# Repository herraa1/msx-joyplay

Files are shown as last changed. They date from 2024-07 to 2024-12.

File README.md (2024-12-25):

# Sony Playstation controller adapter for MSX (msx-joyplay) v2

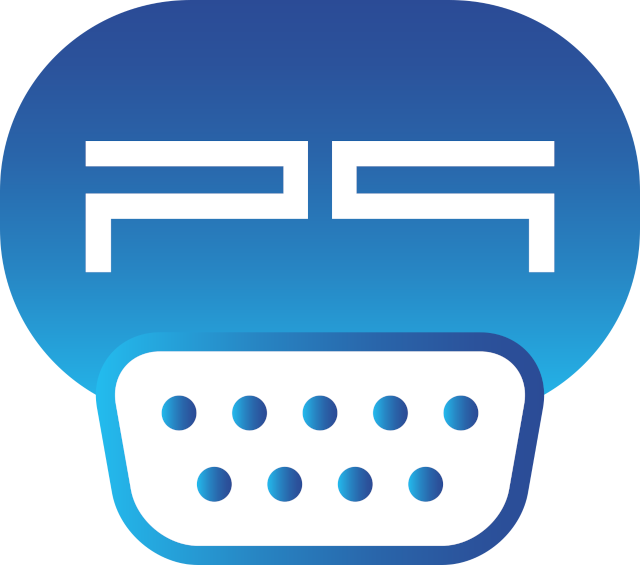
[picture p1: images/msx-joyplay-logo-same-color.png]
[](images/msx-joyplay-logo-same-color.png)

Connect [Sony PlayStation controllers](https://en.wikipedia.org/wiki/PlayStation_(console)#Controllers) to [MSX computers](https://www.msx.org/wiki/).

> [!NOTE]
>
> No build instructions are yet provided, but if you are brave enough go for the [recommended build](#recommended-build).
>

## Introduction

The msx-joyplay v2 is an adapter that allows connecting Sony PlayStation controllers to [MSX general purpose I/O ports](https://www.msx.org/wiki/General_Purpose_port).

The main features of the msx-joyplay v2 adapter are:
* small footprint
* made of widely available electronic components
* behaves as a cord extension between the MSX computer and the Sony PlayStation controller
* uses a female standard DE9 connector on the adapter's MSX joystick side
* uses a PlayStation Controller socket on the adapter's Sony PlayStation controller side
* no need for external power supply, the adapter draws current from the MSX port
* low power consumption (<20mA)
* serial debug provides information about the operation of the adapter

## [Hardware](hardware/kicad/)

The msx-joyplay v2 adapter uses an [Atmega328p](https://en.wikipedia.org/wiki/ATmega328) to convert the [Sony PlayStation SPI-like controller signalling](https://store.curiousinventor.com/guides/PS2) to the [MSX joystick standard signalling](https://www.msx.org/wiki/Joystick_control).

A two-sided printed circuit board (PCB) is used to put together all components:
* An Atmega328p as the main MCU working at +3.3V and clocked at 8MHz
* An AMS1117-3.3 regulator to convert the 5V from the joystick port to the 3.3V used for the Atmega328p chip and the PlayStation controller
* Two 74LS03 quad 2-input NAND gates with open collectors to completely mimic the standard MSX joystick behavior
* A PTC fuse to minimize damage to the MSX computer in case something goes wrong with the board
* Several additional required components (crystal, diode, leds, resistors, ceramic capacitors and a tantalum capacitor)
* An angled PSX socket is used to directly connect the Sony PlayStation controller
* A PH2.0 connector is used to connect the MSX cable extension
* A 2.54 pitch debug header is added for serial debug and programming
* An ICSP header is provided for burning a bootloader or to flash the chip using a hardware programmer

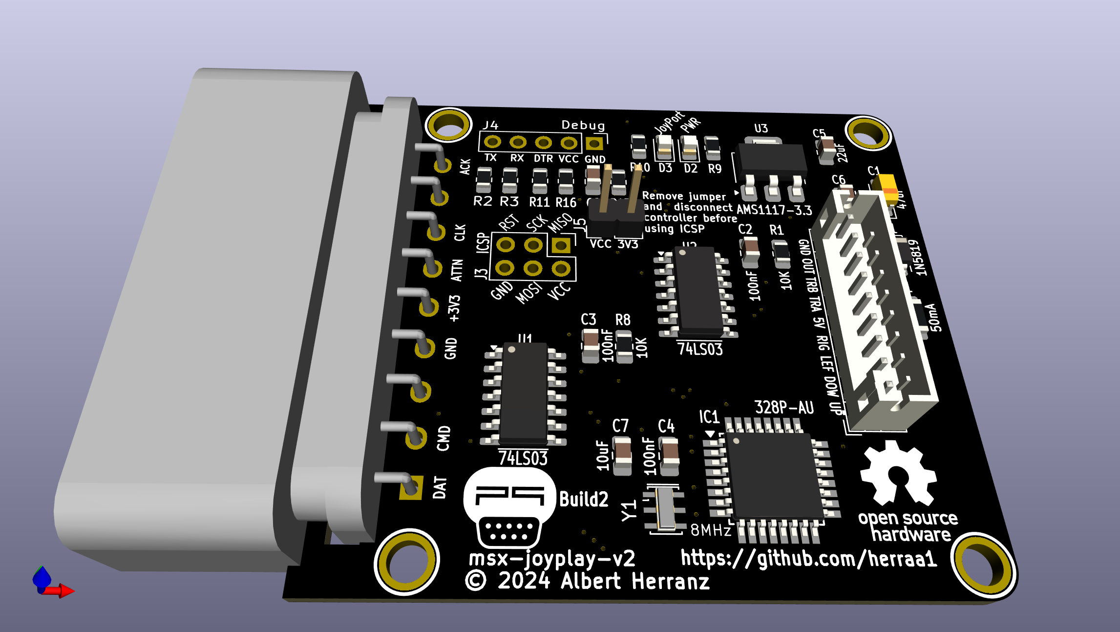
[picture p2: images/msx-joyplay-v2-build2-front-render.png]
[](images/msx-joyplay-v2-build2-front-render.png)
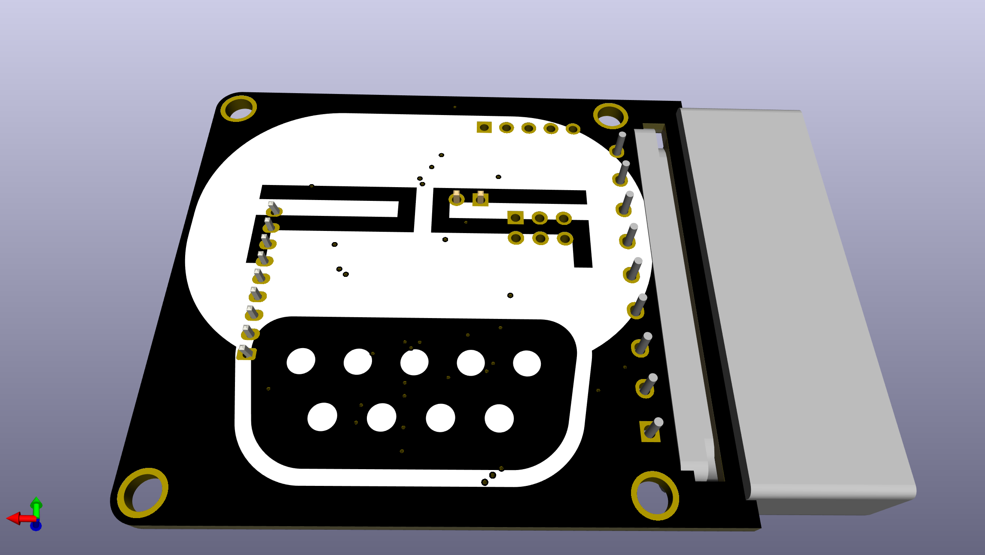
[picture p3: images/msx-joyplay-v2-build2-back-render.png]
[](images/msx-joyplay-v2-build2-back-render.png)

Connection to the MSX general purpose I/O port is implemented using a DE9 joystick extension cable with a female DE9 connector on one side and a loose end on the other side.
The MSX joystick extension cable loose end is wired according to the following pinout mapping.

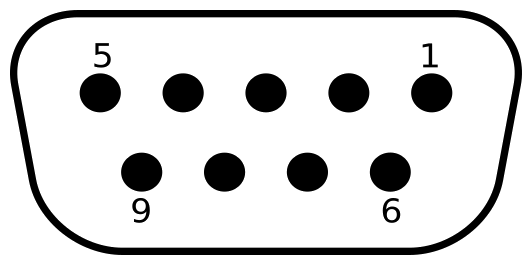
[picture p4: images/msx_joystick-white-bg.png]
| [](images/msx_joystick-white-bg.png) |
|:--|
| MSX joystick connector pinout, from controller plug side |

| MSX side pin | Cable color (may vary) | Signal |
| --- | --- | --- |
| 5 | Brown | +5v |
| 4 | Orange | RIGHT  |
| 3 | Grey | LEFT |
| 2 | Black | DOWN |
| 1 | Red | UP |
| 6 | Green | TRIGA  |
| 7 | White | TRIGB  |
| 8 | Blue | OUT |
| 9 | Yellow | GND |

The msx-joyplay-v2 is fully compatible with MSX joysticks and honors the pin8 (OUT) signal.

The adapter uses open collector outputs (using 74LS03 Quad 2-Input NAND gates with open collector outputs) which makes the adapter safer [^2] than the
standard MSX joystick schematic depicted in the MSX Technical Data Book, as it avoids a series of undesired conditions that can lead to bus contention/short circuits.

Power is drawn from the +5V signal of the MSX general purpose I/O port, which is capable of delivering up to 50mA [^1].
The msx-joyplay v2 draws below 20mA from the port when a controller is connected, so it is on the safe side. Anyway, the msx-joyplay adapter uses a Positive Temperature Coeficient (PTC) resettable fuse of 50mA (F1) to limit current in case something goes wrong.

Also on the power side, a [1N5819 Schottky diode](https://www.diodes.com/assets/Datasheets/1N5819HW.pdf) (D1) is used to avoid leaking current from the msx-joyplay adapter to the MSX in case power is applied to one of the VCC pins available on the ICSP or Debug headers while the adapter is plugged into an MSX.

Connection to the Sony PlayStation controller is done via a Sony PlayStation controller socket.

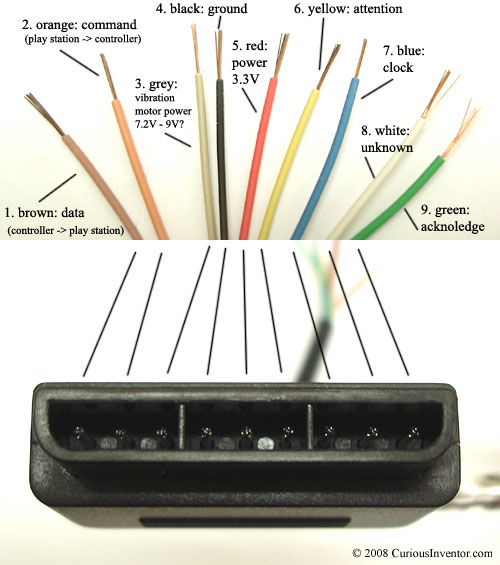
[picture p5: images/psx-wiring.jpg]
| [](images/psx-wiring.jpg) |
|:--|
| Sony PlayStation connector pinout, from Sony PlayStation controller side |

| PSX socket pin | Cable color official | Signal | Comment |
| --- | ---| --- | --- |
| 1 | Brown | DAT  / MISO  | data line, controller -> msx, open-collector signal |
| 2 | Orange | CMD  / MOSI  | cmd line, msx -> controller, uses 3v3 logic |
| 3 | Grey | RUMBLE POWER | 7.6V power, not used (rumble not supported) |
| 4 | Black | GND | ground |
| 5 | Red | +3V3 | +3V3 power |
| 6 | Yellow | ATTN / SS | select line, msx -> controller, uses 3v3 logic |
| 7 | Blue | CLK  / SCK | clock line, msx -> controller, uses 3v3 logic |
| 8 | n/c | | |
| 9 | Green | ACK | ack line, controller -> msx, open-collector signal |

The Sony PlayStation controller uses 3.3V for power and logic, except for the rumble motor which uses 7.6V.

Power for the Sony PlayStation controller is provided by the 3.3V regulator on the msx-joyplay board.

### Recommended Build

Please, use [msx-joyplay-v2 Build2](#build2) for making new boards if you want something field-tested.

### [Build2](hardware/kicad/msx-joyplay-v2-build2)

[Bill Of Materials (BoM)](https://html-preview.github.io/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)

The Build2 adapter mimics completely the standard MSX joystick behaviour:

* When pin8 is HIGH, the adapter puts all stick and triggers signals in high impedance mode irrespective of their status (as if stick and triggers were not hold in the standard MSX joystick schematic), which become HIGH on the MSX side via the MSX PSG related circuitry pull-ups (matching the expected behavior)
* When pin8 is LOW
  * if a stick direction or trigger is hold, the corresponding signal is pulled down to GND causing it to be LOW (matching the expected behavior)
  * if a stick direction or trigger is not hold, the corresponding signal is put in high impedance mode, which becomes HIGH on the MSX side via the MSX PSG related circuitry pull-ups (matching the expected behaviour)

This build uses discrete logic components to honor the pin8 signaling (two [74LS03DR quad 2-input positive-nand gates with open collector outputs](https://www.ti.com/lit/ds/symlink/sn74ls03.pdf)) and uses open collector outputs which makes the adapter safer [^2] than the standard MSX joystick schematic depicted in the MSX Technical Data Book, as it avoids a series of undesired conditions that can lead to bus contention/short circuits.

## [Firmware](firmware/msx-joyplay-v2/)

The msx-joyplay v2 adapter firmware uses [SukkoPera's PsxNewLib library](https://github.com/SukkoPera/PsxNewLib) to read the Sony PlayStation controller status.

The following elements are used as inputs:
* digital pad (D-Pad), as direction arrows
* left analog pad, as direction arrows
* square button, as Trigger 1
* triangle button, as Trigger 2

Those elements' status are processed by the msx-joyplay firmware and transformed into MSX general purpose I/O port's signals on the fly.

## [Enclosure](enclosure/)

### Acrylic

A simple acrylic enclosure design for the project is provided to protect the electronic components and provide strain relief for the extension cords.

The enclosure uses a 3mm acrylic sheet.

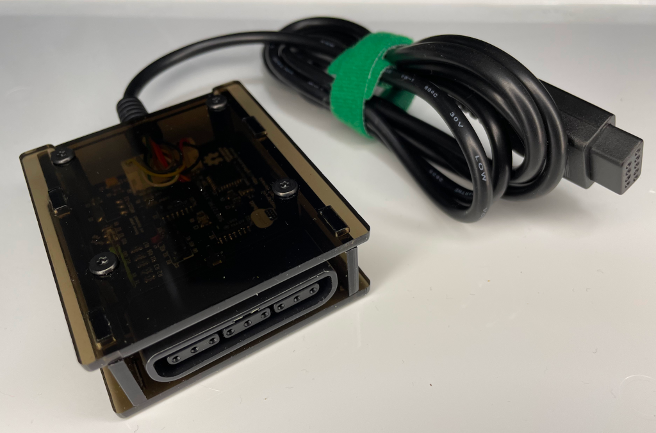
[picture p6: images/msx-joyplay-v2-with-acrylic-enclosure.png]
[](images/msx-joyplay-v2-with-acrylic-enclosure.png)

## References

MSX general purpose I/O port
* https://www.msx.org/wiki/General_Purpose_port

PlayStation controller pinout and protocol
* https://store.curiousinventor.com/guides/PS2

Atmega328p pinout
- https://camo.githubusercontent.com/18796d8b7673e3b6c14b6bdfb61d86b58c6f0d670398973abd4207afce960277/68747470733a2f2f692e696d6775722e636f6d2f6e6177657145362e6a7067

SukkoPera PsxNewLib project
* https://github.com/SukkoPera/PsxNewLib

[^1]: https://www.msx.org/wiki/General_Purpose_port
[^2]: https://www.msx.org/wiki/Joystick/joypad_controller (see "Undesired Conditions")

## Image Sources

* https://www.oshwa.org/open-source-hardware-logo/
* https://en.wikipedia.org/wiki/File:Numbered_DE9_Diagram.svg

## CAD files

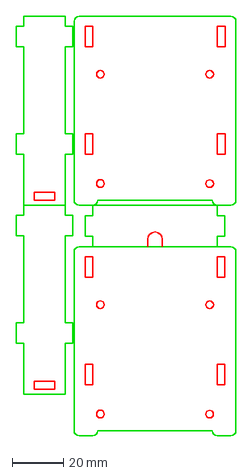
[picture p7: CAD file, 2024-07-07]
enclosure/msx-joyplay-v2-case-acrylic-3mm-ready-to-lasercut.dxf
86.1 x 164.3 mm

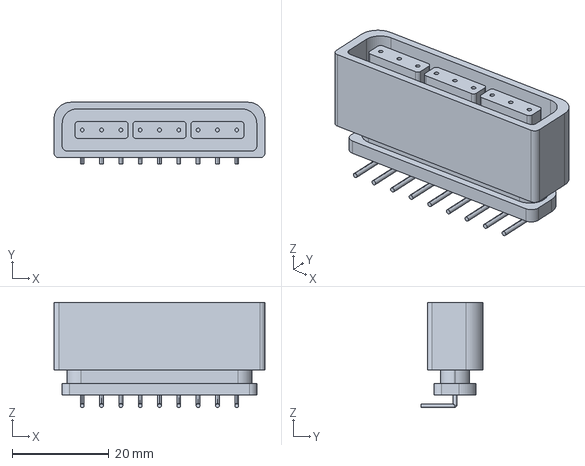
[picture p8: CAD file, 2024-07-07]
hardware/kicad/msx-joyplay-v2-build2/compo/3dmodels/ps-connector-female/pritesh.stp
43.7 x 12.8 x 21.8 mm

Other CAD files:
hardware/kicad/msx-joyplay-v2-build2/compo/3dmodels/ps-connector-female/pritesh.igs

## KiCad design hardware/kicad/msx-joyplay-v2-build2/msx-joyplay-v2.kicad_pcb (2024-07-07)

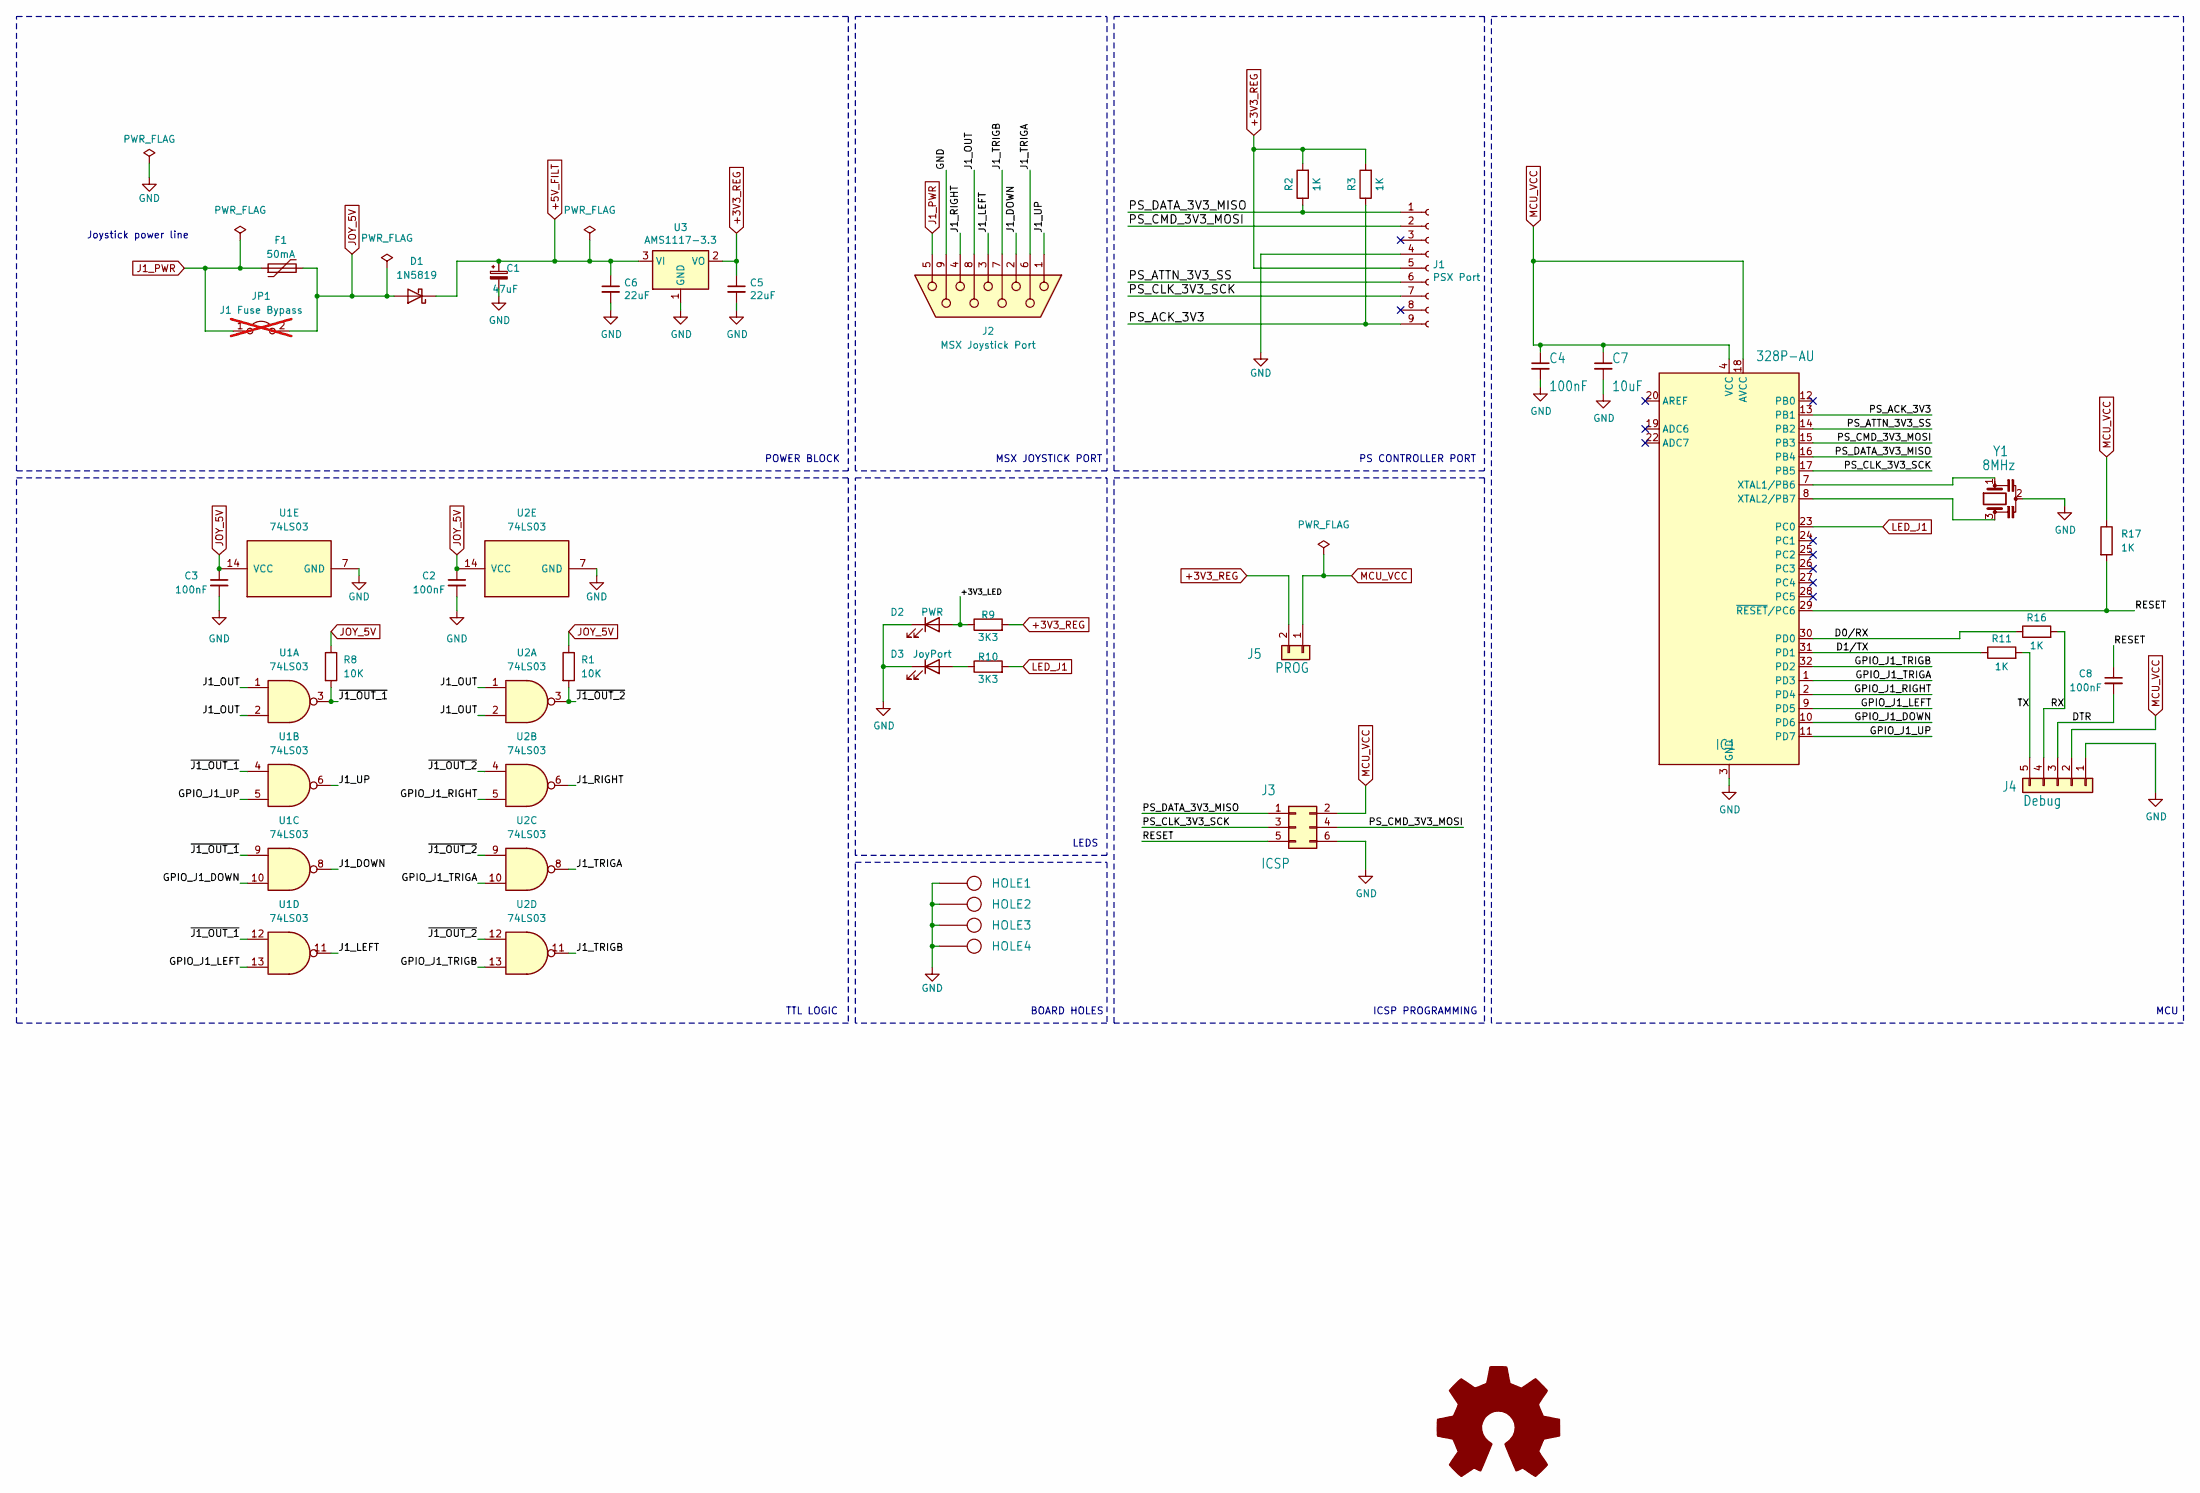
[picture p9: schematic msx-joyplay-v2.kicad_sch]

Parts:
C1: 47uF; CP_EIA-3216-18_Kemet-A_Pad1.58x1.35mm_HandSolder
C2, C3, C4, C8: 100nF; C_0805_2012Metric_Pad1.18x1.45mm_HandSolder
C5, C6: 22uF; C_0805_2012Metric_Pad1.18x1.45mm_HandSolder
C7: 10uF; C_0805_2012Metric_Pad1.18x1.45mm_HandSolder
D1: 1N5819; D_SOD-123
D2: PWR; LED_0805_2012Metric_Pad1.15x1.40mm_HandSolder
D3: JoyPort; LED_0805_2012Metric_Pad1.15x1.40mm_HandSolder
F1: 50mA; Fuse_1206_3216Metric_Pad1.42x1.75mm_HandSolder
HOLE1, HOLE2, HOLE3, HOLE4: HOLE; Hole_3mm
IC1: 328P-AU; TQFP-32_7x7mm_P0.8mm
J1: PSX Port; PSX_Pad_Connector
J2: MSX Joystick Port; JST_PH_B9B-PH-K_1x09_P2.00mm_Vertical
J3: ICSP; PinHeader_2x03_P2.54mm_Vertical
J4: Debug; PinHeader_1x05_P2.54mm_Vertical
J5: PROG; PinHeader_1x02_P2.54mm_Vertical
JP1: J1 Fuse Bypass; PinHeader_1x02_P2.54mm_Vertical; not fitted
R1, R8: 10K; R_0805_2012Metric_Pad1.20x1.40mm_HandSolder
R2, R3, R11, R16, R17: 1K; R_0805_2012Metric_Pad1.20x1.40mm_HandSolder
R9: 3K3; R_0805_2012Metric_Pad1.20x1.40mm_HandSolder
R10: 3K3; R_0805_2012Metric_Pad1.20x1.40mm_HandSolder; LCSC C4310
SYM1: Logo_Open_Hardware_Large; OSHW-Logo_7.5x8mm_SilkScreen
U1, U2: 74LS03; SOIC-14_3.9x8.7mm_P1.27mm
U3: AMS1117-3.3; SOT-223-3_TabPin2
Y1: 8MHz; Resonator_SMD_Murata_CSTxExxV-3Pin_3.0x1.1mm_HandSoldering

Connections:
+3V3_REG: C5.1, J1.5, J5.2, R2.2, R3.2, R9.2, U3.2 (VO)
+5V_FILT: C1.1, C6.1, D1.1 (K), U3.3 (VI)
/+3V3_LED: D2.2 (A), R9.1
/D0/RX: IC1.30 (PD0), R16.1
/D1/TX: IC1.31 (PD1), R11.1
/DTR: C8.2, J4.3
/GPIO_J1_DOWN: IC1.10 (PD6), U1.10
/GPIO_J1_LEFT: IC1.9 (PD5), U1.13
/GPIO_J1_RIGHT: IC1.2 (PD4), U2.5
/GPIO_J1_TRIGA: IC1.1 (PD3), U2.10
/GPIO_J1_TRIGB: IC1.32 (PD2), U2.13
/GPIO_J1_UP: IC1.11 (PD7), U1.5
/J1_DOWN: J2.2, U1.8
/J1_LEFT: J2.3, U1.11
/J1_OUT: J2.8, U1.1, U1.2, U2.1, U2.2
/J1_RIGHT: J2.4, U2.6
/J1_TRIGA: J2.6, U2.8
/J1_TRIGB: J2.7, U2.11
/J1_UP: J2.1, U1.6
/PS_ACK_3V3: IC1.13 (PB1), J1.9, R3.1
/PS_ATTN_3V3_SS: IC1.14 (PB2), J1.6
/PS_CLK_3V3_SCK: IC1.17 (PB5), J1.7, J3.3
/PS_CMD_3V3_MOSI: IC1.15 (PB3), J1.2, J3.4
/PS_DATA_3V3_MISO: IC1.16 (PB4), J1.1, J3.1, R2.1
/RESET: C8.1, IC1.29 (~RESET/PC6), J3.5, R17.2
/RX: J4.4, R16.2
/TX: J4.5, R11.2
/~J1_OUT_1: R8.2, U1.3, U1.4, U1.9, U1.12
/~J1_OUT_2: R1.2, U2.3, U2.4, U2.9, U2.12
GND: C1.2, C2.2, C3.2, C4.2, C5.2, C6.2, C7.2, D2.1 (K), D3.1 (K), HOLE1.1, HOLE2.1, HOLE3.1, HOLE4.1, IC1.3 (GND), IC1.5 (GND), IC1.21 (GND), J1.4, J2.9, J3.6, J4.1, U1.7 (GND), U2.7 (GND), U3.1 (GND), Y1.2
J1_PWR: F1.1, J2.5, JP1.1 (A)
JOY_5V: C2.1, C3.1, D1.2 (A), F1.2, JP1.2 (B), R1.1, R8.1, U1.14 (VCC), U2.14 (VCC)
LED_J1: IC1.23 (PC0), R10.2
MCU_VCC: C4.1, C7.1, IC1.4 (VCC), IC1.6 (VCC), IC1.18 (AVCC), J3.2, J4.2, J5.1, R17.1
unnamed: D3.2 (A), R10.1
unnamed: IC1.7 (XTAL1/PB6), Y1.1
unnamed: IC1.8 (XTAL2/PB7), Y1.3

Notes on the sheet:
MCU
LEDS
MSX JOYSTICK PORT
TTL LOGIC
BOARD HOLES
Joystick power line
ICSP PROGRAMMING
PS CONTROLLER PORT
POWER BLOCK

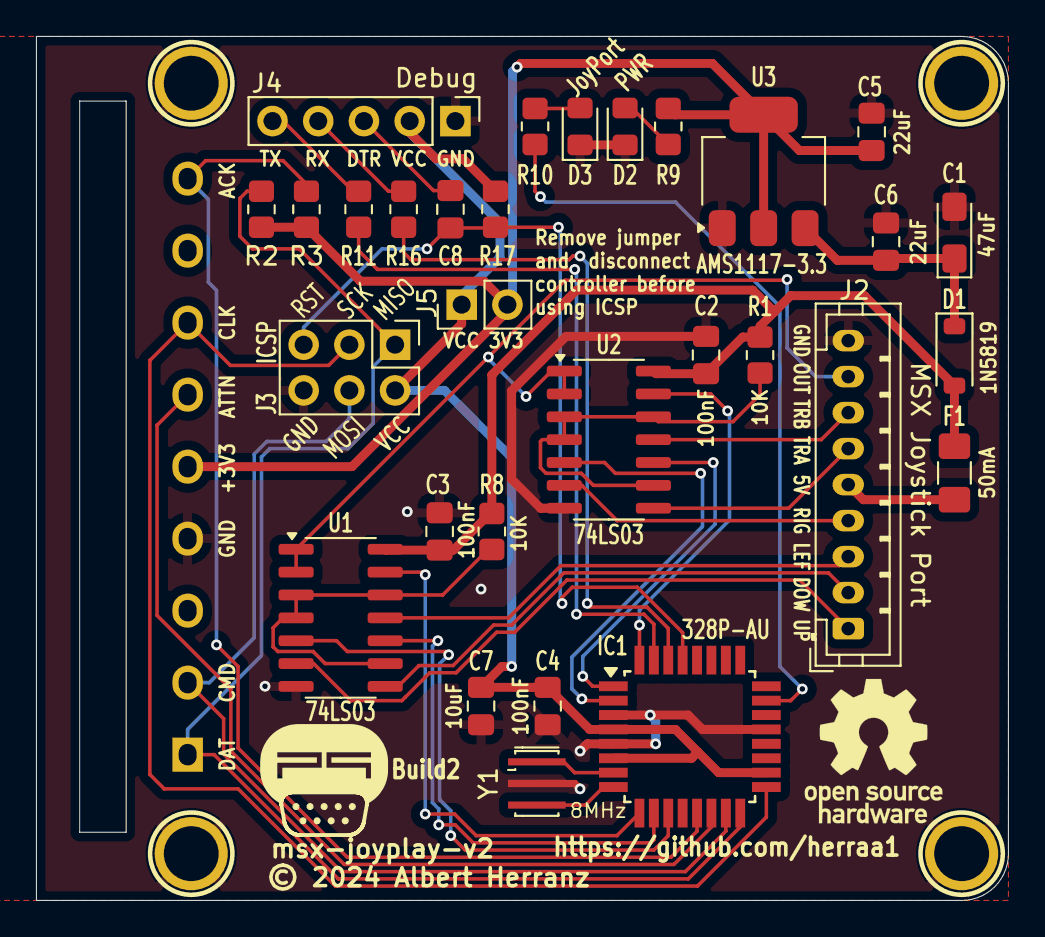
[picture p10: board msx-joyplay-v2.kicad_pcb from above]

Board: 2 copper layers, 54.0 x 48.0 mm, 36 parts (0 on the bottom side), 37 nets.

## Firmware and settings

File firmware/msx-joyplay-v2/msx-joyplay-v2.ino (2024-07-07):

/*
 * msx-joyplay v2, a PlayStation controller to MSX joystick adapter
 * Copyright (C) 2024 Albert Herranz
 *
 * This code is released under GPL V2.0
 *
 * Valid-License-Identifier: GPL-2.0-only
 * SPDX-URL: https://spdx.org/licenses/GPL-2.0-only.html
 *
 * Based on previous work by:
 * - SukkoPera PsxNewLib project, https://github.com/SukkoPera/PsxNewLib
 *
 * Other references:
 * - https://store.curiousinventor.com/guides/PS2
 * - https://www.msx.org/wiki/General_Purpose_port
 * - https://github.com/MCUdude/MiniCore
 * - https://www.arduino.cc/en/software
 */

/*******************************************************************************
 * Copyright (C) 2019-2020 by SukkoPera <software@sukkology.net>               *
 *                                                                             *
 * PsxNewLib is free software: you can redistribute it and/or                  *
 * modify it under the terms of the GNU General Public License as published by *
 * the Free Software Foundation, either version 3 of the License, or           *
 * (at your option) any later version.                                         *
 *                                                                             *
 * PsxNewLib is distributed in the hope that it will be useful,                *
 * but WITHOUT ANY WARRANTY; without even the implied warranty of              *
 * MERCHANTABILITY or FITNESS FOR A PARTICULAR PURPOSE.  See the               *
 * GNU General Public License for more details.                                *
 *                                                                             *
 * You should have received a copy of the GNU General Public License           *
 * along with PsxNewLib. If not, see http://www.gnu.org/licenses.              *
 *******************************************************************************
 */

/*

Built using Arduino 2.2.1
Libraries:
- DigitalIO 1.0.1
- PSXNewLib 0.4.0
Boards:
- Minicore 2.2.2
  - Board: Atmega328
  - BOD 1.8V
  - Bootloader: Yes (UART0)
  - Clock: External 8MHz
  - EEPROM: Retained
  - Compiler LTO: Disabled
  - Variant: 328P/328PA

PSX Pin         Wire   Direction            Type           V     Function           atmega238p/Arduino pin 
--------------- ------ -------------------- -------------- ----- ------------------ ------------
 1 DATA         BROWN  controller -> msx    open-collector 3.3V  miso               16/12
 2 COMMAND      ORANGE msx -> controller                   3.3V  mosi               15/11
 3 RUMBLE POWER GREY                                       7.6V                     unused
 4 GND          BLACK                                                               GND
 5 +3V3         RED                                                                 +3V3
 6 ATTN         YELLOW msx -> controller                   3.3V  ss (slave select)  14/10
 7 CLK          BLUE   msx -> controller                   3.3V  sck                17/13
 8 UNK          n/c                                                                 unused
 9 ACK          GREEN  controller -> msx   open-collector  3.3V                     unused

*/

#include <DigitalIO.h>
#include <PsxControllerHwSpi.h>

#include <avr/pgmspace.h>
typedef const __FlashStringHelper* FlashStr;
typedef const byte* PGM_BYTES_P;
#define PSTR_TO_F(s) reinterpret_cast<const __FlashStringHelper*>(s)

/* SS, Slave Select */
const byte PIN_PS2_ATT = 10;

/* LEDs */
const byte PIN_BUTTONPRESS = A1;    /* not used on current board */
const byte PIN_HAVECONTROLLER = A0; /* green led */

/*
 * Arduino Nano pins for MSX signals.
 * We use PORTD for all MSX joystick arrow and buttons signals.
 * This allows to set them all at the same time.
 */
#define PORT_MSX_JOYSTICK PORTD
#define DDR_MSX_JOYSTICK DDRD

/* Sony Playstation controller pad axis valid range */
#define PSX_AXIS_MIN 0
#define PSX_AXIS_MAX 255

/* MSX general purpose signals as mapped to Arduino Nano PORTD bits */
const int PORT_MSX_JOYSTICK_UP = 7;       /* PD7, MSX joystick pin1 */
const int PORT_MSX_JOYSTICK_DOWN = 6;     /* PD6, MSX joystick pin2 */
const int PORT_MSX_JOYSTICK_LEFT = 5;     /* PD5, MSX joystick pin3 */
const int PORT_MSX_JOYSTICK_RIGHT = 4;    /* PD4, MSX joystick pin4 */
const int PORT_MSX_JOYSTICK_TRIGGER1 = 3; /* PD3, MSX joystick pin6 */
const int PORT_MSX_JOYSTICK_TRIGGER2 = 2; /* PD2, MSX joystick pin7 */

volatile uint8_t curr_msx_joystick_signals = 0x00;

/*
 * Discrete thresholds for Sony Playstation joystick analog pad axis:
 * - Values below the min threshold on the horizontal/vertical axis indicate
 *   left/down active, respectively.
 * - Values above the max threshold on the horizontal/vertical axis indicate
 *   right/up active, respectively.
 */
int axis_threshold_min, axis_threshold_max;

PsxControllerHwSpi<PIN_PS2_ATT> psx;
boolean haveController = false;

/* serial output width control */
uint8_t output_width_count = 0;

#ifdef DEBUG
const char buttonSelectName[] PROGMEM = "Select";
const char buttonL3Name[] PROGMEM = "L3";
const char buttonR3Name[] PROGMEM = "R3";
const char buttonStartName[] PROGMEM = "Start";
const char buttonUpName[] PROGMEM = "Up";
const char buttonRightName[] PROGMEM = "Right";
const char buttonDownName[] PROGMEM = "Down";
const char buttonLeftName[] PROGMEM = "Left";
const char buttonL2Name[] PROGMEM = "L2";
const char buttonR2Name[] PROGMEM = "R2";
const char buttonL1Name[] PROGMEM = "L1";
const char buttonR1Name[] PROGMEM = "R1";
const char buttonTriangleName[] PROGMEM = "Triangle";
const char buttonCircleName[] PROGMEM = "Circle";
const char buttonCrossName[] PROGMEM = "Cross";
const char buttonSquareName[] PROGMEM = "Square";

const char* const psxButtonNames[PSX_BUTTONS_NO] PROGMEM = {
  buttonSelectName,
  buttonL3Name,
  buttonR3Name,
  buttonStartName,
  buttonUpName,
  buttonRightName,
  buttonDownName,
  buttonLeftName,
  buttonL2Name,
  buttonR2Name,
  buttonL1Name,
  buttonR1Name,
  buttonTriangleName,
  buttonCircleName,
  buttonCrossName,
  buttonSquareName
};

void print_hex8(uint8_t data)
{
  char tmp[2 + 1];
  byte nibble;

  nibble = (data >> 4) | 48;
  tmp[0] = (nibble > 57) ? nibble + (byte)39 : nibble;
  nibble = (data & 0x0f) | 48;
  tmp[1] = (nibble > 57) ? nibble + (byte)39 : nibble;
  tmp[2] = 0;

  Serial.print(tmp);
}

void print_hex16(uint16_t data)
{
  print_hex8((uint8_t)(data >> 8));
  print_hex8((uint8_t)(data & 0xff));
}

byte psxButtonToIndex(PsxButtons psxButtons)
{
  byte i;

  for (i = 0; i < PSX_BUTTONS_NO; ++i) {
    if (psxButtons & 0x01) {
      break;
    }

    psxButtons >>= 1U;
  }

  return i;
}

FlashStr getButtonName(PsxButtons psxButton)
{
  FlashStr ret = F("");

  byte b = psxButtonToIndex(psxButton);
  if (b < PSX_BUTTONS_NO) {
    PGM_BYTES_P bName = reinterpret_cast<PGM_BYTES_P>(pgm_read_ptr(&(psxButtonNames[b])));
    ret = PSTR_TO_F(bName);
  }

  return ret;
}

void dumpButtons(PsxButtons psxButtons)
{
  static PsxButtons lastB = 0;

  if (psxButtons != lastB) {
    lastB = psxButtons;  // Save it before we alter it

    Serial.print(F("Pressed: "));

    for (byte i = 0; i < PSX_BUTTONS_NO; ++i) {
      byte b = psxButtonToIndex(psxButtons);
      if (b < PSX_BUTTONS_NO) {
        PGM_BYTES_P bName = reinterpret_cast<PGM_BYTES_P>(pgm_read_ptr(&(psxButtonNames[b])));
        Serial.print(PSTR_TO_F(bName));
      }
      psxButtons &= ~(1 << b);

      if (psxButtons != 0) {
        Serial.print(F(", "));
      }
    }

    Serial.println();
  }
}

void dumpAnalog(const char* str, const byte x, const byte y)
{
  Serial.print(str);
  Serial.print(F(" analog: x = "));
  Serial.print(x);
  Serial.print(F(", y = "));
  Serial.println(y);
}
#endif

void print_rolling_sequence(void)
{
  static char rolling_chars[] = { '-', '\\', '|', '/' };
  static uint8_t rolling_index = 0;

  //Serial.write(8);
  Serial.print(rolling_chars[rolling_index++]);
  if (rolling_index >= sizeof(rolling_chars))
    rolling_index = 0;
}

const char ctrlTypeUnknown[] PROGMEM = "Unknown";
const char ctrlTypeDualShock[] PROGMEM = "Dual Shock";
const char ctrlTypeDsWireless[] PROGMEM = "Dual Shock Wireless";
const char ctrlTypeGuitHero[] PROGMEM = "Guitar Hero";
const char ctrlTypeOutOfBounds[] PROGMEM = "(Out of bounds)";

const char* const controllerTypeStrings[PSCTRL_MAX + 1] PROGMEM = {
  ctrlTypeUnknown,
  ctrlTypeDualShock,
  ctrlTypeDsWireless,
  ctrlTypeGuitHero,
  ctrlTypeOutOfBounds
};

inline void __update_msx_signals(uint8_t signals)
{
  /*
     * signals variable bit definitions
     * - bit set   : joystick arrow/button is pressed
     *               configure associated GPIO as HIGH/OUTPUT (logic "1")
     * - bit unset : joystick arrow/button is not pressed
     *               configure associated GPIO as LOW/OUTPUT (logic "0")
     */

  /* write all signal states at once to MSX side */
  PORT_MSX_JOYSTICK = (signals);
  DDR_MSX_JOYSTICK = (~0);
}

void setup()
{
  int axis_threshold;

  __update_msx_signals(curr_msx_joystick_signals);

  /*
     * Calculate PSX controller analog pad thresholds.
     * Analog pad needs to be pushed from its origin in one direction at least
     * 1/6 of the complete run to get active
     */
  axis_threshold = (PSX_AXIS_MAX - PSX_AXIS_MIN) / 3;
  axis_threshold_min = PSX_AXIS_MIN + axis_threshold;
  axis_threshold_max = PSX_AXIS_MAX - axis_threshold;

  fastPinMode(PIN_BUTTONPRESS, OUTPUT);
  fastPinMode(PIN_HAVECONTROLLER, OUTPUT);

  Serial.begin(115200);
  Serial.println(F("msx-joyplay-v2 20240629_1"));

  delay(300);
}

void loop() {
  static byte slx, sly, srx, sry;

  fastDigitalWrite(PIN_HAVECONTROLLER, haveController);

  if (!haveController) {
    curr_msx_joystick_signals = 0x00;
    __update_msx_signals(curr_msx_joystick_signals);

    /* write rolling sequence while not connected */
    print_rolling_sequence();
    /* wrap output at 80 columns ... */
    if (output_width_count++ > 79) {
      output_width_count = 0;
      Serial.println("");
    }

    if (psx.begin()) {
      Serial.println(F("Controller found!"));
      output_width_count = 0;
      delay(300);
      if (!psx.enterConfigMode()) {
        Serial.println(F("Cannot enter config mode"));
      } else {
        PsxControllerType ctype = psx.getControllerType();
        PGM_BYTES_P cname = reinterpret_cast<PGM_BYTES_P>(pgm_read_ptr(&(controllerTypeStrings[ctype < PSCTRL_MAX ? static_cast<byte>(ctype) : PSCTRL_MAX])));
        Serial.print(F("Controller Type is: "));
        Serial.println(PSTR_TO_F(cname));

        if (!psx.enableAnalogSticks()) {
          Serial.println(F("Cannot enable analog sticks"));
        }

        if (!psx.enableAnalogButtons()) {
          Serial.println(F("Cannot enable analog buttons"));
        }

        if (!psx.exitConfigMode()) {
          Serial.println(F("Cannot exit config mode"));
        }
      }

      haveController = true;
    }
  } else {
    if (!psx.read()) {
      Serial.println(F("Controller lost :("));
      haveController = false;
    } else {
      PsxButtons psxButtons = psx.getButtonWord();
      fastDigitalWrite(PIN_BUTTONPRESS, !!psxButtons);
#ifdef DEBUG
      dumpButtons(psxButtons);
#endif

      byte lx, ly;
      psx.getLeftAnalog(lx, ly);
      if (lx != slx || ly != sly) {
#ifdef DEBUG
        dumpAnalog("Left", lx, ly);
#endif
        slx = lx;
        sly = ly;
      }

#ifdef DEBUG
      byte rx, ry;
      psx.getRightAnalog(rx, ry);
      if (rx != srx || ry != sry) {
        dumpAnalog("Right", rx, ry);
        srx = rx;
        sry = ry;
      }
#endif

      uint8_t msx_joystick_signals = 0;

      if (!!(psxButtons & PSB_PAD_UP))
        msx_joystick_signals |= (1 << PORT_MSX_JOYSTICK_UP);
      if (!!(psxButtons & PSB_PAD_DOWN))
        msx_joystick_signals |= (1 << PORT_MSX_JOYSTICK_DOWN);
      if (!!(psxButtons & PSB_PAD_LEFT))
        msx_joystick_signals |= (1 << PORT_MSX_JOYSTICK_LEFT);
      if (!!(psxButtons & PSB_PAD_RIGHT))
        msx_joystick_signals |= (1 << PORT_MSX_JOYSTICK_RIGHT);
      if (!!(psxButtons & PSB_SQUARE))
        msx_joystick_signals |= (1 << PORT_MSX_JOYSTICK_TRIGGER1);
      if (!!(psxButtons & PSB_TRIANGLE))
        msx_joystick_signals |= (1 << PORT_MSX_JOYSTICK_TRIGGER2);

      /* before activating UP check that DOWN is not activated */
      if ((ly < axis_threshold_min) && !(msx_joystick_signals & (1 << PORT_MSX_JOYSTICK_DOWN)))
        msx_joystick_signals |= (1 << PORT_MSX_JOYSTICK_UP);

      /* before activating DOWN check that UP is not activated */
      if ((ly > axis_threshold_max) && !(msx_joystick_signals & (1 << PORT_MSX_JOYSTICK_UP)))
        msx_joystick_signals |= (1 << PORT_MSX_JOYSTICK_DOWN);

      /* before activating LEFT check that RIGHT is not activated */
      if ((lx < axis_threshold_min) && !(msx_joystick_signals & (1 << PORT_MSX_JOYSTICK_RIGHT)))
        msx_joystick_signals |= (1 << PORT_MSX_JOYSTICK_LEFT);

      /* before activating RIGHT check that LEFT is not activated */
      if ((lx > axis_threshold_max) && !(msx_joystick_signals & (1 << PORT_MSX_JOYSTICK_LEFT)))
        msx_joystick_signals |= (1 << PORT_MSX_JOYSTICK_RIGHT);

      curr_msx_joystick_signals = msx_joystick_signals;

      __update_msx_signals(curr_msx_joystick_signals);
    }
  }

  delay(1000 / 60);
}

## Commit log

2024-07-08 readme: small fix, add picture with acrylic enclosure
2024-12-25 readme: add microprocessor voltage and clock
2024-12-25 readme: mention SPI as the controller protocol

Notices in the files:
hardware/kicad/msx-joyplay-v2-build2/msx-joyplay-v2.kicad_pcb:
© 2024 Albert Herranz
